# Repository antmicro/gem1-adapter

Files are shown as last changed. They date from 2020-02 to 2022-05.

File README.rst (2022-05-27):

GEM1 Adapter
============

Copyright (c) 2020 `Antmicro <https://www.antmicro.com>`_





This repository contains PCB design files for an adapter board accommodating the GEM1 chip created jointly by `zGlue <http://zglue.com>`_ and `Antmicro <http://www.antmicro.com>`_.
The `GEM1 design <https://zglue.com/design-automation/oci/project/gem1>`_ utilizes the zGlue ZiP chiplet technology and has been prepared using zGlue's `ChipBuilder <http://chipbuilder.zglue.com/>`_ tool.
The design has been produced as a single integrated circuit in the LGA-96 package.

The GEM1 chip contains the following components located on a dynamically reconfigurable interposer:

* 2x Lattice ``ICE40UP5K-UWG30ITR`` FPGAs used for processing and system control
* 32Mbit SPI FLASH memory
* 10-channel DPDT MIPI switch allowing to connect a 2-lane MIPI CSI-2 interface either to the processing FPGA or to external output (pass-through mode)
* 12MHz system clock generator 
* Internal LDOs and power management unit providing 1V2, 1V8, 2V5, 3V3 voltages

Power is supplied to the chip from a single ``VUSB`` voltage of 5 VDC.
The actual configuration of the system running inside the GEM1 zip depends on the configuration routing file that is uploaded to the ``Smart fabric`` interposer.
Also, pin functions of the LGA package may vary depending on the uploaded routing file.
The board break-routes signals for the MIPI CSI-2 interfaces (Input and Output), along with the internal flash and FPGA configuration interfaces, control signals and power supplies.

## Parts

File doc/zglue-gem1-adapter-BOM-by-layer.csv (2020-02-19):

Reference | Quantity | Value | Footprint | Manufacturer | MPN | Layer
TP1 TP10 TP11 TP12 TP14 TP15 TP16 TP17 TP2 TP3 TP4 TP5 TP7 TP8 TP9 | 15 | TP_SMD1MM | Testpoint_smd_1mm |  |  | Virtual
C1 | 1 | C_10u_0402 | 0402-cap | TDK | C1005X5R0J106M050BC | Unknown
C10 C11 C12 C14 C5 C6 C7 C8 C9 | 9 | C_100n_0402_6V3 | 0402-cap | Walsin | 0402X104K6R3CT | Unknown
C13 C15 | 2 | C_10n_0402 | 0402-cap | AVX | 04025G103ZAT2A | Unknown
C2 C3 C4 | 3 | C_2u2_0402 | 0402-cap | TDK | C1005X5R1A225K050BC | Unknown
J1 J2 | 2 | 543630489 | 543630489 | Molex | 543630489 | Unknown
R1 R15 R16 R17 R18 R19 R2 R20 R21 R22 R25 R26 R3 R4 R5 R6 R7 R8 | 18 | R_0R_0402 | 0402-res | PANASONIC | ERJ2GE0R00X | Unknown
R10 R12 R14 R23 R9 | 5 | R_100R_0402 | 0402-res | BOURNS | CR0402-FX-1000GLF | Unknown
R11 | 1 | R_1k5_0402 | 0402-res | PANASONIC_ELECTRONIC_COMPONENTS | ERJ2RKF1501X | Unknown
R13 | 1 | R_10k_0402 | 0402-res | VISHAY | CRCW040210K0FKEDHP | Unknown
R24 | 1 | R_220R_0402 | 0402-res | TE_CONNECTIVITY_/_NEOHM | CRG0402J220R | Unknown
U1 | 1 | zGlue-GEM1 | Z-Glue_LGA-96 | zGlue/TSMC | GEM1 | Unknown

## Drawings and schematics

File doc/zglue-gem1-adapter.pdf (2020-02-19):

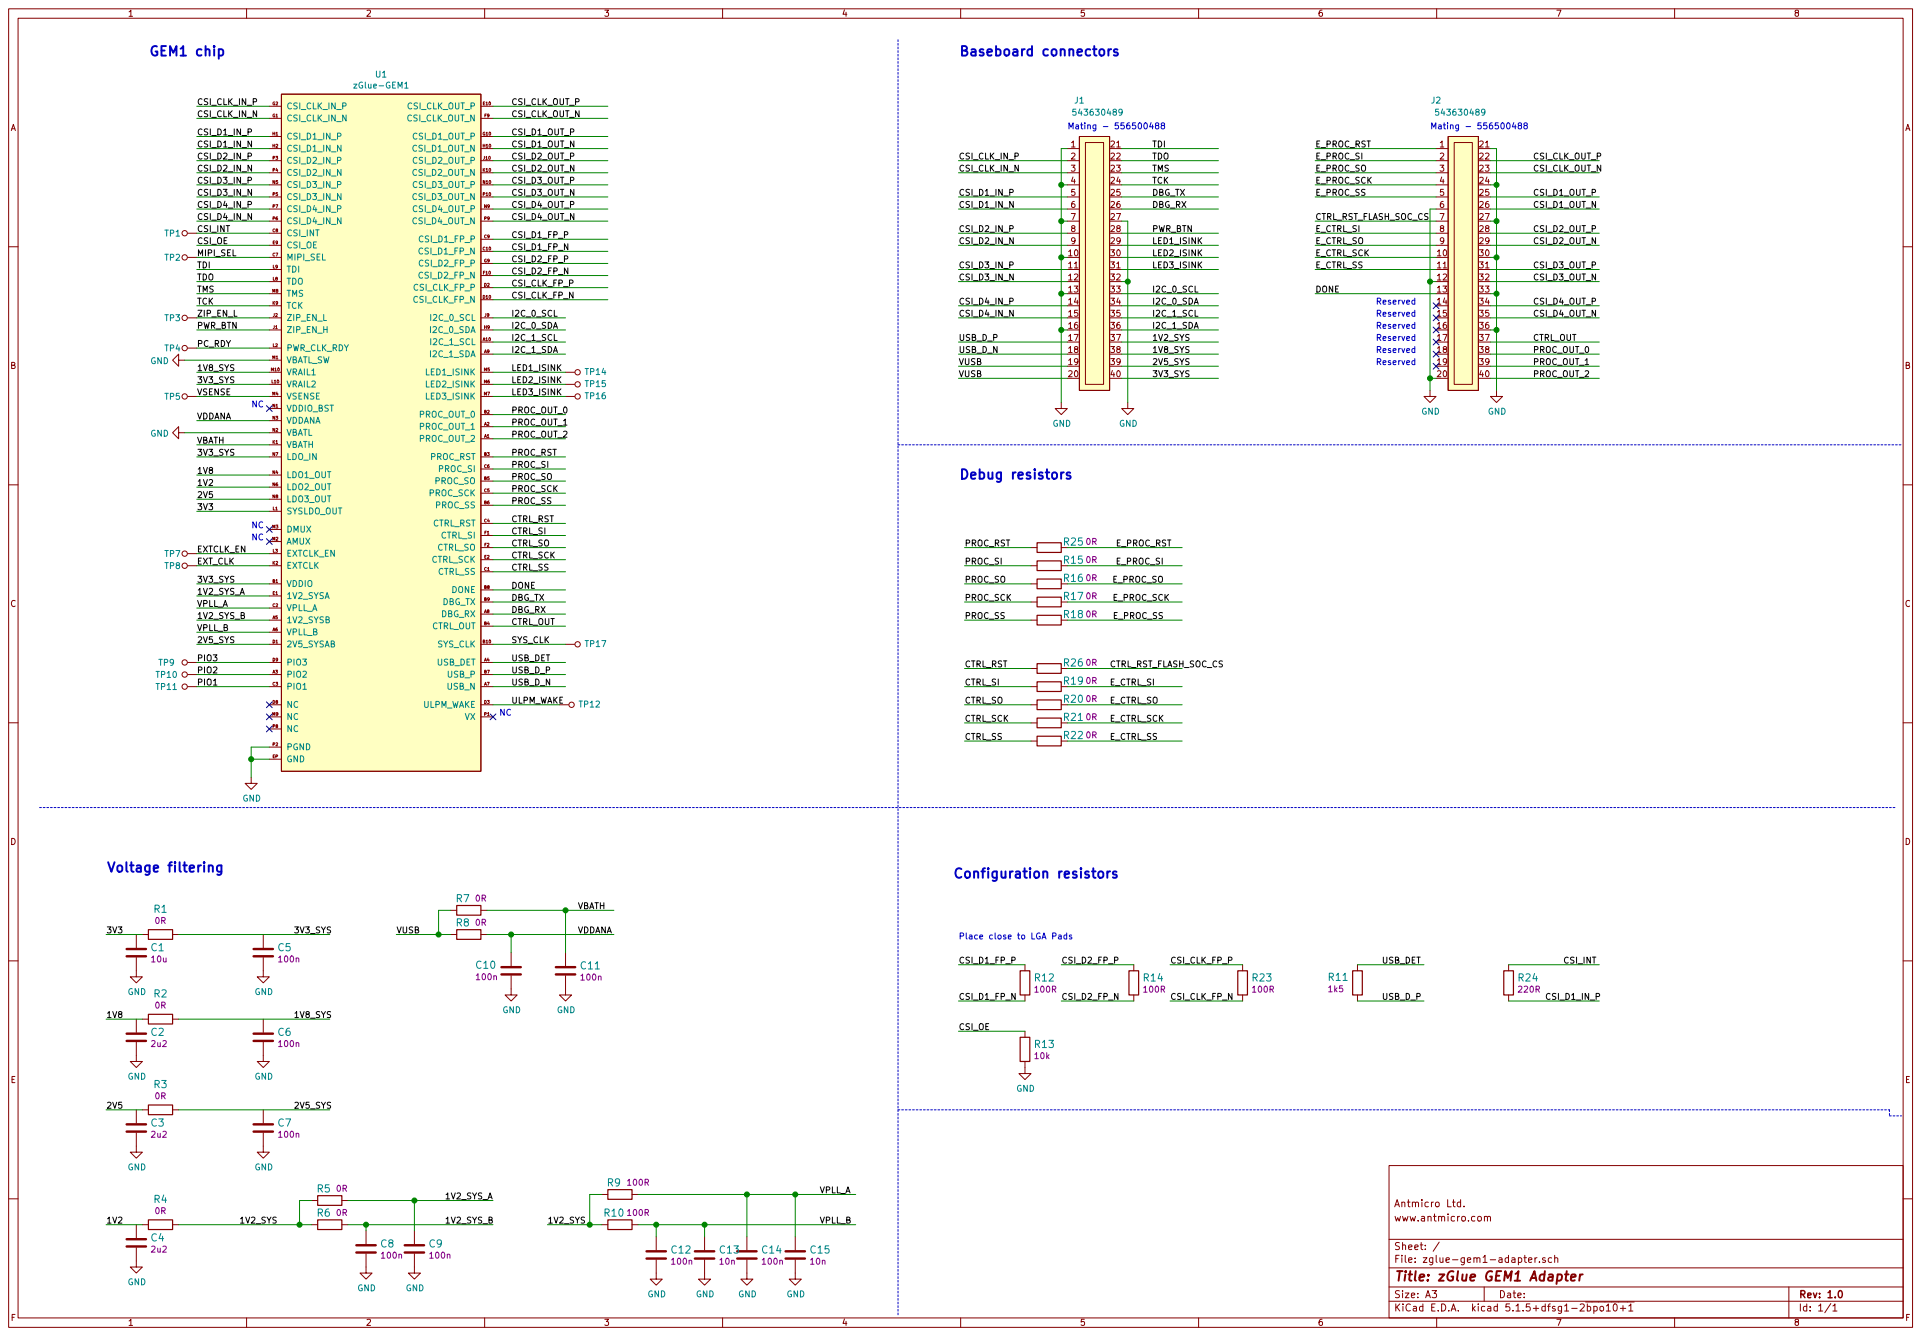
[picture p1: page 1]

Place close to LGA Pads Configuration resistors

Antmicro Ltd.
File: zglue-gem1-adapter.sch Sheet: / www.antmicro.com

Id: 1/1 Title: zGlue GEM1 Adapter

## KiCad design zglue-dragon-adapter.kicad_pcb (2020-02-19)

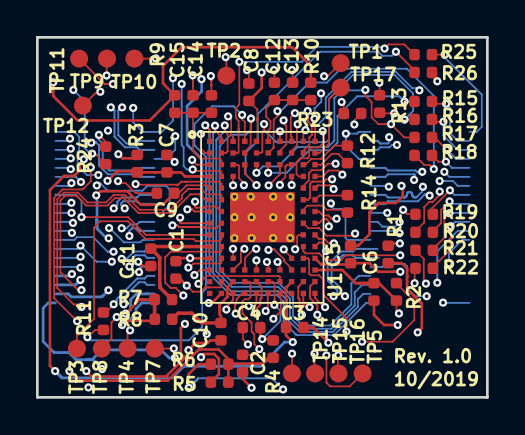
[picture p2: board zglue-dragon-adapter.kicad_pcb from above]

Board: 6 copper layers, 25.0 x 20.0 mm, 59 parts (0 on the bottom side), 97 nets.

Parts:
C1: C_10u_0402; 0402-cap
C2, C3, C4: C_2u2_0402; 0402-cap
C5, C6, C7, C8, C9, C10, C11, C12, C14: C_100n_0402_6V3; 0402-cap
C13, C15: C_10n_0402; 0402-cap
J1, J2: 543630489
R1, R2, R3, R4, R5, R6, R7, R8, R15, R16, R17, R18, R19, R20, R21, R22, R25, R26: R_0R_0402; 0402-res
R9, R10, R12, R14, R23: R_100R_0402; 0402-res
R11: R_1k5_0402; 0402-res
R13: R_10k_0402; 0402-res
R24: R_220R_0402; 0402-res
TP1, TP2, TP3, TP4, TP5, TP7, TP8, TP9, TP10, TP11, TP12, TP14, TP15, TP16, TP17: TP_SMD1MM; Testpoint_smd_1mm
U1: zGlue-Dragon; Z-Glue_LGA-96

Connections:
/1V2: C4.1, R4.1, U1.N6
/1V2_SYS: J1.37, R4.2, R5.1, R6.1, R9.1, R10.1
/1V2_SYS_A: C9.1, R5.2, U1.E1
/1V2_SYS_B: C8.1, R6.2, U1.A5
/1V8: C2.1, R2.1, U1.N4
/1V8_SYS: C6.1, J1.38, R2.2, U1.M10
/2V5: C3.1, R3.1, U1.N8
/2V5_SYS: C7.1, J1.39, R3.2, U1.D1
/3V3: C1.1, R1.1, U1.L1
/3V3_SYS: C5.1, J1.40, R1.2, U1.B1, U1.L10, U1.N7
/CSI_CLK_FP_N: R23.2, U1.D10
/CSI_CLK_FP_P: R23.1, U1.D2
/CSI_CLK_IN_N: J1.3, U1.G1
/CSI_CLK_IN_P: J1.2, U1.G2
/CSI_CLK_OUT_N: J2.23, U1.F9
/CSI_CLK_OUT_P: J2.22, U1.E10
/CSI_D1_FP_N: R12.2, U1.C10
/CSI_D1_FP_P: R12.1, U1.C9
/CSI_D1_IN_N: J1.6, U1.H2
/CSI_D1_IN_P: J1.5, R24.2, U1.H1
/CSI_D1_OUT_N: J2.26, U1.H10
/CSI_D1_OUT_P: J2.25, U1.G10
/CSI_D2_FP_N: R14.2, U1.F10
/CSI_D2_FP_P: R14.1, U1.G9
/CSI_D2_IN_N: J1.9, U1.P4
/CSI_D2_IN_P: J1.8, U1.P3
/CSI_D2_OUT_N: J2.29, U1.K10
/CSI_D2_OUT_P: J2.28, U1.J10
/CSI_D3_IN_N: J1.12, U1.P5
/CSI_D3_IN_P: J1.11, U1.N5
/CSI_D3_OUT_N: J2.32, U1.P10
/CSI_D3_OUT_P: J2.31, U1.N10
/CSI_D4_IN_N: J1.15, U1.P6
/CSI_D4_IN_P: J1.14, U1.P7
/CSI_D4_OUT_N: J2.35, U1.P9
/CSI_D4_OUT_P: J2.34, U1.N9
/CSI_INT: R24.1, TP1.1, U1.C8
/CSI_OE: R13.1, U1.E9
/CTRL_OUT: J2.37, U1.B4
/CTRL_RST: R26.1, U1.C4
/CTRL_RST_FLASH_SOC_CS: J2.7, R26.2
/CTRL_SCK: R21.1, U1.E2
/CTRL_SI: R19.1, U1.F1
/CTRL_SO: R20.1, U1.F2
/CTRL_SS: R22.1, U1.C1
/DBG_RX: J1.26, U1.A8
/DBG_TX: J1.25, U1.B9
/DONE: J2.13, U1.B8
/EXTCLK_EN: TP7.1, U1.L3
/EXT_CLK: TP8.1, U1.K2
/E_CTRL_SCK: J2.10, R21.2
/E_CTRL_SI: J2.8, R19.2
/E_CTRL_SO: J2.9, R20.2
/E_CTRL_SS: J2.11, R22.2
/E_PROC_RST: J2.1, R25.2
/E_PROC_SCK: J2.4, R17.2
/E_PROC_SI: J2.2, R15.2
/E_PROC_SO: J2.3, R16.2
/E_PROC_SS: J2.5, R18.2
/I2C_0_SCL: J1.33, U1.J9
/I2C_0_SDA: J1.34, U1.H9
/I2C_1_SCL: J1.35, U1.A10
/I2C_1_SDA: J1.36, U1.A9
/LED1_ISINK: J1.29, TP14.1, U1.M5
/LED2_ISINK: J1.30, TP15.1, U1.M6
/LED3_ISINK: J1.31, TP16.1, U1.M7
/MIPI_SEL: TP2.1, U1.C7
/PC_RDY: TP4.1, U1.L2
/PIO1: TP11.1, U1.C3
/PIO2: TP10.1, U1.A3
/PIO3: TP9.1, U1.D9
/PROC_OUT_0: J2.38, U1.B2
/PROC_OUT_1: J2.39, U1.A2
/PROC_OUT_2: J2.40, U1.A1
/PROC_RST: R25.1, U1.B3
/PROC_SCK: R17.1, U1.C5
/PROC_SI: R15.1, U1.C6
/PROC_SO: R16.1, U1.B5
/PROC_SS: R18.1, U1.B6
/PWR_BTN: J1.28, U1.J1
/SYS_CLK: TP17.1, U1.B10
/TCK: J1.24, U1.K9
/TDI: J1.21, U1.L9
/TDO: J1.22, U1.L8
/TMS: J1.23, U1.M8
/ULPM_WAKE: TP12.1, U1.D3
/USB_DET: R11.1, U1.A4
/USB_D_N: J1.18, U1.A7
/USB_D_P: J1.17, R11.2, U1.B7
/VBATH: C11.1, R7.2, U1.K1
/VDDANA: C10.1, R8.2, U1.N3
/VPLL_A: C14.1, C15.1, R9.2, U1.C2
/VPLL_B: C12.1, C13.1, R10.2, U1.A6
/VSENSE: TP5.1, U1.M4
/VUSB: J1.19, J1.20, R7.1, R8.1
/ZIP_EN_L: TP3.1, U1.J2
GND: C1.2, C2.2, C3.2, C4.2, C5.2, C6.2, C7.2, C8.2, C9.2, C10.2, C11.2, C12.2, C13.2, C14.2, C15.2, J1.1, J1.4, J1.7, J1.10, J1.13, J1.16, J1.27, J1.32, J2.6, J2.12, J2.20, J2.21, J2.24, J2.27, J2.30, J2.33, J2.36, R13.2, U1.EP, U1.M1, U1.N2, U1.P2

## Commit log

2019-10-02 Added zGlue symbol library, added symbol to schematic
    [_saved_zglue-dragon-baseboard.sch]
2019-10-02 Added .gitignore
    [_saved_zglue-dragon-baseboard.sch, zglue-dragon-baseboard.sch]
2019-10-02 Added CSI signals
    [zglue-dragon-baseboard.sch]
2019-10-02 Added MIPI termination
    [zglue-dragon-baseboard.sch]
2019-10-02 Added voltage filtering
    [zglue-dragon-baseboard.sch]
2020-02-19 Added b2b connectors
    [zglue-dragon-baseboard.sch]
2020-02-19 Tied LED signals to B2B connector, fixed CSI lane naming
    [zglue-dragon-adapter.sch]
2020-02-19 Added QSPI flash signals to unify with GEM2 adapter
    [zglue-dragon-adapter.sch]
2020-02-19 QSPI signals marked as reserved
    [zglue-dragon-adapter.sch]
2020-02-19 Added NC to specified signals from ZiP
    [zglue-dragon-adapter.sch]
2020-02-19 Added CSI INT
    [zglue-dragon-adapter.sch]
2020-02-19 Finished component placement
    Fixed G10 pad name on LGA-96 footprint
    [_saved_zglue-dragon-adapter.sch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]
2020-02-19 Added LGA-96 STEP model
    [zglue-dragon-adapter.kicad_pcb]
2020-02-19 Moved some capacitors and resistors away from LGA-96 chip
    [_saved_zglue-dragon-adapter.sch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]
2020-02-19 Rotated PCB by 180 deg to match chip logo orientation
    [zglue-dragon-adapter-B.CrtYd.gbr, zglue-dragon-adapter-B.Mask.gbr, zglue-dragon-adapter-B.Paste.gbr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]
2020-02-19 Changed PCB stackup to 6-layer, added stackup table, changed design rules
    [zglue-dragon-adapter-B.CrtYd.gbr, zglue-dragon-adapter-B.Mask.gbr, zglue-dragon-adapter-B.Paste.gbr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]
2020-02-19 Routing finished
    [zglue-dragon-adapter-B.CrtYd.gbr, zglue-dragon-adapter-B.Mask.gbr, zglue-dragon-adapter-B.Paste.gbr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]
2020-02-19 Added second ground plane, updated gerbers
    [zglue-dragon-adapter-B.CrtYd.gbr, zglue-dragon-adapter-B.Mask.gbr, zglue-dragon-adapter-B.Paste.gbr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]
2020-02-19 Layout polishing, connected PROC_RST and CTRL_RST to chip via 0R
    [zglue-dragon-adapter-B.CrtYd.gbr, zglue-dragon-adapter-B.Mask.gbr, zglue-dragon-adapter-B.Paste.gbr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]
2020-02-19 Added testpad for VSENSE
    [zglue-dragon-adapter-B.CrtYd.gbr, zglue-dragon-adapter-B.Mask.gbr, zglue-dragon-adapter-B.Paste.gbr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]
2020-02-19 Moved C1,2,3,4 closer to LDO output pins
    [zglue-dragon-adapter-B.CrtYd.gbr, zglue-dragon-adapter-B.Mask.gbr, zglue-dragon-adapter-B.Paste.gbr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]
2020-02-19 Modified LGA-96 thermal pad on paste layer
    [zglue-dragon-adapter-B.CrtYd.gbr, zglue-dragon-adapter-B.Mask.gbr, zglue-dragon-adapter-B.Paste.gbr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]
2020-02-19 Design files used for PCB manufacturing
    [zglue-dragon-adapter-B.CrtYd.gbr, zglue-dragon-adapter-B.Mask.gbr, zglue-dragon-adapter-B.Paste.gbr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]
2020-02-19 Library cleanup
    [zglue-dragon-adapter.kicad_pcb, zglue-dragon-adapter.sch]
2020-02-19 Updated LGA-96 stencil pattern
    [zglue-dragon-adapter.kicad_pcb]
2020-02-19 Updated naming convention, updated README
    [zglue-gem1-adapter-BOM-by-layer.csv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]
2020-02-20 Updated directory structure
    [zglue-gem1-adapter-BOM-by-layer.csv]
